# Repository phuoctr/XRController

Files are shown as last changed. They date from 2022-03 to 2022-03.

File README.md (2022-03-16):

# Tutorial: Thumb-mounted controller

This thumb-mounted controller is an input device for using in extended reality (XR) environments, it operates by sensing user’s thumb gestures in which thumb contact and movements are processed using the output data from 2 or more force sensitive resistors and a gyroscope, recognised gestures are send to a XR device via Bluetooth Low Energy.

## Materials

- Adafruit Feather nRF52840 sense: this is a bluetooth low energy (BLE) development board which comes with built-in accelerator, gyroscope and magnetometer. Another equivalent board is Arduino Nano 33 BLE. The Adafruit Feather Sense can be found at [Adafruit website](https://www.adafruit.com/product/4516)

- 2*Force sensitive resistors: resistors with minimum sensitve of 30gr is recommend for better gesture sensing. The force sensistive resistors can be purchased for example on [Mouser](https://eu.mouser.com/ProductDetail/Ohmite/FSR05CE?qs=0lSvoLzn4L9hUdjZ8RLKtw==).

- 2* 10,000Ohms resistors. The resistors can be bought easily from the internet.
- 3.3V Li-Po battery. For this controller, a 500mAH battery is used but it can also be powered by the microUSB port but keep it in mind that because the power consumption is not very significant so some battery banks will only work for few second before it stop powering the controller.
- A housing for the board: this housing is based on the board holder from Adafruit and a thumb cover to mount the controller on. The stl file for this housing can be found in this repo. This housing is modified from the [Adafruit Feather case](https://www.thingiverse.com/thing:1367270/files).
- A housing for the battery: a wrist band for mounting the battery. The stl file for this band can be found in this repo.

## Force Sensitive Resistors

Force sensitive resistors play an important role on this controller for touch recognition including swiping and pressing. To use the force sensors, we need to make a voltage divider circuit as the figure below, a 3V power is connect to one pin on each force sensor, and on the other pin the analog input and ground is connected.



## Arduino program

To program the Adafruit Feather Sense board, you need to use Arduino with Adafruit nRF52 library imported, the process can be done following this tutorial from Adafruit. Along with the nRF52 library, the Adafruit_LSM6DS33.h library need to be imported to Arduino to get output data from the gyroscope. After the Arduino IDE is set up, connect the board to your computer via microUSB cable, download this Arduino sketch  and run it. 
Housing

The housing comprises of two parts, one for holding the Feather Sense board and the other for mounting user’s thumb, under the thumb mount, the force sensitive parts of two force sensitive resistors are stiched as illustrated in the figure below:


The controller can be powered either by connecting to a computer or using an external battery, a battery wristband is designed for mounting the battery.

## Gestures
At the moment, this controller supports following gestures, in future version of the hardware and software I hope to include more gestures
- Swiping left/right on a touch zone
- Swiping up/down
- Quick press
- Long press

A working demo for this controller can be found [here](https://phuoctrinh.com/ar-input-prototype), in this demo an AR Unity application for iPad is developed which communicate with the XR controller over BLE.

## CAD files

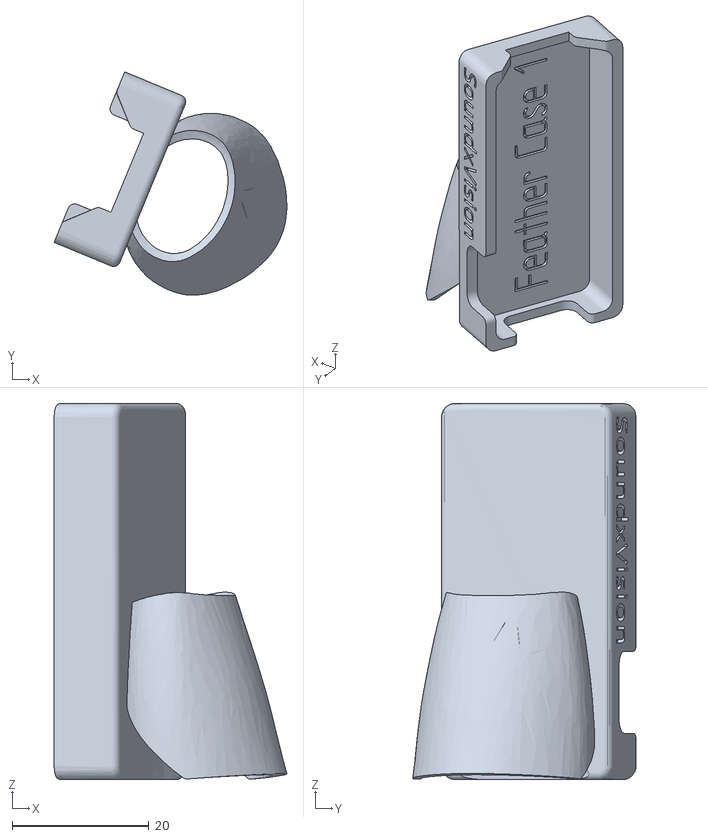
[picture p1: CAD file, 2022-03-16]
ThumbMountedDeviceHousing.stl
34.1 x 32.7 x 55.0

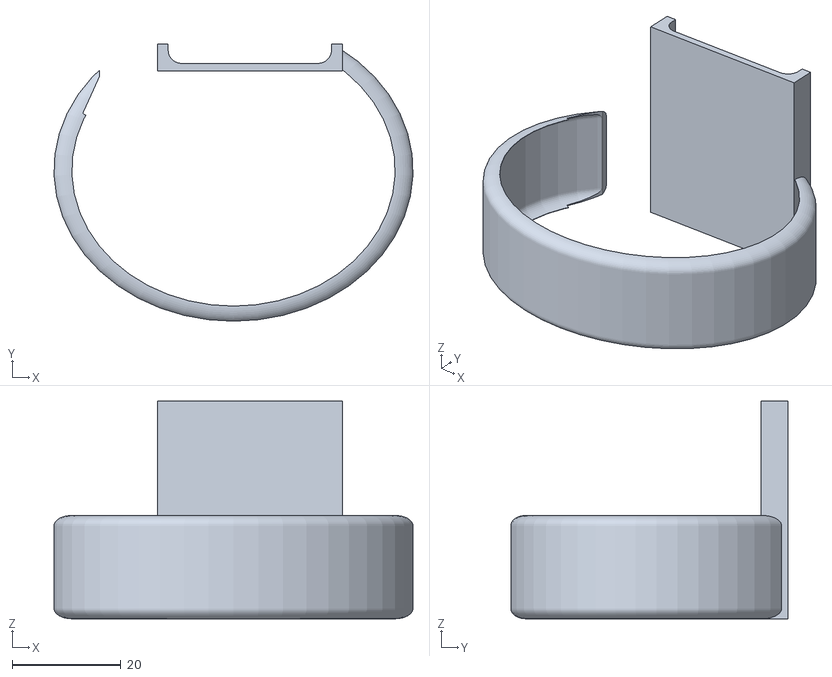
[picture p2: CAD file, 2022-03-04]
BatteryBand.stl
66.0 x 51.0 x 40.0

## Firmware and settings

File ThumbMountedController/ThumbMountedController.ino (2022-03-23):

#include <bluefruit.h>
#include "ThumbMountedController.h"
#include <Adafruit_LSM6DS33.h>  // Accel + gyro

//Sensors definition
Adafruit_LSM6DS33 lsm6ds33; // Gyro and Accel

// BLE Service
BLEService        service                    (HID_UUID(0x0000));
BLECharacteristic deviceInfoCharacteristic  (HID_UUID(0x0001));
BLECharacteristic hidCharacteristic (HID_UUID(0x0002));

int state = IDLING;
int timer0 = TOUCH_RELEASE_DURATION; // timer for touch releasing
int timer1 = SWIPING_UPDATE_INTERVAL; // time slot for angle calc
int timer2 = MINIMUM_PRESS_DOWN_DURATION; // timer for press sensing

// timer references
uint32_t timerRef0; // timestamp for touch releasing
uint32_t timerRef1; // timestamp for angle calc
uint32_t timerRef2; // timestamp for pressing

// touch release
bool firstPointRelease = false;
bool secondPointRelease = false;

//z Axis rotation
float zAxisRotation;

void setupSensors(void)
{
  
  lsm6ds33.begin_I2C(); // begin accel + gyro
  // set lowest range
  lsm6ds33.setGyroRange(LSM6DS_GYRO_RANGE_500_DPS);
  // Increase I2C speed to 400 Khz
  Wire.setClock(400000);
}

void setupBLE(void){
  const char deviceName[13] = "XRController";
  Bluefruit.configPrphBandwidth(BANDWIDTH_MAX);
  Bluefruit.begin();
  Bluefruit.setTxPower(4);    // Check bluefruit.h for supported values
  Bluefruit.setName(deviceName);
  service.begin();
  
  Bluefruit.Periph.setConnInterval(16, 24);
  Bluefruit.Periph.setConnectCallback(connect_callback);
  Bluefruit.Periph.setDisconnectCallback(disconnect_callback);

  hidCharacteristic.setProperties(CHR_PROPS_NOTIFY);
  hidCharacteristic.setPermission(SECMODE_OPEN, SECMODE_NO_ACCESS);
  hidCharacteristic.setFixedLen(1 * sizeof(byte)); //  data length for state, 1 byte
  hidCharacteristic.begin();
   
  }
  
void startAdv(void)
{
  // Advertising packet
  Bluefruit.Advertising.addFlags(BLE_GAP_ADV_FLAGS_LE_ONLY_GENERAL_DISC_MODE);
  Bluefruit.Advertising.addTxPower();

  // Include bleuart 128-bit uuid
  Bluefruit.Advertising.addService(service);
  Bluefruit.Advertising.addName();
  Bluefruit.Advertising.restartOnDisconnect(true);
  Bluefruit.Advertising.setInterval(32, 244);    // in unit of 0.625 ms
  Bluefruit.Advertising.setFastTimeout(30);      // number of seconds in fast mode
  Bluefruit.Advertising.start(0);                // 0 = Don't stop advertising after n seconds  
}




uint8_t updateState(void){
  // read the input on analog pin 0:
  int AIN0 = analogRead(A0); // first force sensor
  int AIN1 = analogRead(A1); // second force sensor
  
  sensors_event_t event; // gyro event
  lsm6ds33.getGyroSensor()->getEvent(&event);
  
  switch (state) {

    case IDLING: // Default state, listen for change on first and second force sensors
      if (AIN0 >= NORMAL_TOUCH || AIN1 >= NORMAL_TOUCH) state = TOUCHING;
      break;

    case TOUCHING: // When contact is detected on at least one force sensor
      if (AIN0 >= NORMAL_TOUCH && AIN1 >= NORMAL_TOUCH) break; // Not yet built
      // first point sensing
      if (AIN0 >= NORMAL_TOUCH && AIN0 < HARD_PRESS) { // Light-medium pressure on 1s force sensor
        state = FIRST_ZONE_TOUCHING; // Set state to swiping
        timerRef1 = millis(); // Start time reference for calculating z Axis rotation
      }
      else if (AIN0 >= HARD_PRESS){ 
        state = FIRST_ZONE_START_PRESS; // Hard press on first force sensor
        timerRef2 = millis();
      }
      // second point sensing
      if (AIN1 >= NORMAL_TOUCH && AIN1 < HARD_PRESS) { // Light-medium pressure on 2 force sensor
        state = SECOND_ZONE_TOUCHING; // Set state to swiping
        timerRef1 = millis();
      }
      else if (AIN1 >= HARD_PRESS) {
        state = SECOND_ZONE_START_PRESS; // Hard press on first force sensor
        timerRef2 = millis();
      }
      break;

    case FIRST_ZONE_TOUCHING:
      if (AIN0 <= NONE_CONTACT) { 
        // pressure down below 10 => touch release
        state = TOUCH_RELEASE;
        firstPointRelease = true;
        timerRef0 = millis(); // start timer
      }
      else if (AIN0 >= HARD_PRESS) { // pressure > 600 => pressing
        state = FIRST_ZONE_START_PRESS;
        timerRef2 = millis(); // timer ref for pressing
      }
      else {
        if (timer1 > 0) {
          zAxisRotation += event.gyro.z * SENSORS_RADS_TO_DPS * (millis() - timerRef1) / 1000;          // Integration from angular velocity to rotation
          timer1 -= millis() - timerRef1;
          timerRef1 = millis();
          if (zAxisRotation >= SWIPING_ANGLE) {
            state = FIRST_ZONE_LEFT;
            zAxisRotation = 0;
          }
          else if (zAxisRotation <= -SWIPING_ANGLE) {
            state = FIRST_ZONE_RIGHT;
            zAxisRotation = 0;
          }
        }
        else {
          timer1 = SWIPING_UPDATE_INTERVAL;
          zAxisRotation = 0;
        }
      }
      break;

    case FIRST_ZONE_LEFT:
      state = TOUCHING;
      break;

    case FIRST_ZONE_RIGHT:
      state = TOUCHING;
      break;

    case FIRST_ZONE_START_PRESS:
      // If pressure down to 10 and below, just switch to touch release
      if (AIN0 <= NONE_CONTACT){ 
        state = IDLING;
        break;
      }
      // The timer count down from 500
      if (timer2 > 0) {
        timer2 -= millis() - timerRef2; //On first time, the timerRef2 was initialized on TOUCHING
        timerRef2 = millis(); //Re-initialized for next loop
        if (AIN0 < HARD_PRESS) state = FIRST_ZONE_QUICK_PRESS; //if pressing shorter than 500ms => press once
      }
      else { 
          timer2 = 0;
          state = FIRST_ZONE_PRESS_DOWN;
      }
      break;

    case FIRST_ZONE_QUICK_PRESS:
      // Do something with single tap
      timer2 = MINIMUM_PRESS_DOWN_DURATION; // reset timer 2
      state = TOUCHING;
      break;

    case FIRST_ZONE_PRESS_DOWN:
      // keep state until force below 600
      if(AIN0 < HARD_PRESS) {
        state = TOUCHING;
        timer2 = MINIMUM_PRESS_DOWN_DURATION; // reset timer 2
        }
      break;

    case SECOND_ZONE_TOUCHING:
      if (AIN1 <= NONE_CONTACT) {
        state = TOUCH_RELEASE;
        secondPointRelease = true;
        timerRef0 = millis();
      }
      else if (AIN1 >= HARD_PRESS) {
        state = SECOND_ZONE_START_PRESS;
        timerRef2 = millis();
      }
      else {
        if (timer1 > 0) {
          zAxisRotation += event.gyro.z * SENSORS_RADS_TO_DPS * (millis() - timerRef1) / 1000;
          timer1 -= millis() - timerRef1;
          timerRef1 = millis();
          if (zAxisRotation >= SWIPING_ANGLE/2) {
            state = SECOND_ZONE_LEFT;
            zAxisRotation = 0;
            Serial.println(">>>>>>>>>>>>>>>>>>>>>>>>>>>>>>>>>>>>>>>>>>>>>>>>>>>>>>>");
          }
          else if (zAxisRotation <= -SWIPING_ANGLE/3) {
            state = SECOND_ZONE_RIGHT;
            zAxisRotation = 0;
            Serial.println("<<<<<<<<<<<<<<<<<<<<<<<<<<<<<<<<<<<<<<<<<<<<<<<<<<<<<<<");
          }
        }
        else {
          timer1 = SWIPING_UPDATE_INTERVAL;
          zAxisRotation = 0;
        }
      }
      break;

    case SECOND_ZONE_LEFT:
      //Do sth
      state = TOUCHING;
      break;

    case SECOND_ZONE_RIGHT:
      //Do sth
      state = TOUCHING;
      break;

    case SECOND_ZONE_START_PRESS:
//      // If pressure down to 10 and below, just switch to switch release
      if (AIN1 <= NONE_CONTACT){ 
        state = IDLING;
        break;
      }
//      // The timer count down for the duration of defined minimum press down duration
      if (timer2 > 0) {
        timer2 -= millis() - timerRef2; //On first time, the timerRef2 was initialized on TOUCHING
        timerRef2 = millis(); //Re-initialized for next loop
        if (AIN1 < HARD_PRESS) state = SECOND_ZONE_QUICK_PRESS; //if pressing shorter than 100ms => press once
      }
      else { 
        timer2 = 0;
        state = SECOND_ZONE_PRESS_DOWN;
      }
      break;

    case SECOND_ZONE_QUICK_PRESS:
      // Do something with single tap
      timer2 = MINIMUM_PRESS_DOWN_DURATION; // reset timer 2
      state = TOUCHING;
      break;

    case SECOND_ZONE_PRESS_DOWN:
      // keep state until force below 600
      if(AIN1 < HARD_PRESS) {
        state = TOUCHING;
        timer2 = MINIMUM_PRESS_DOWN_DURATION; // reset timer 2
        }
      break;
      
    case TOUCH_RELEASE:
      timer0 -= (millis() - timerRef0);
      timerRef0 = millis();
      if (timer0 <= 0){
          timer0 = TOUCH_RELEASE_DURATION;
          state = IDLING;
          // After touch release interval without any touch, reset first/secondTouchRelease bool
          firstPointRelease = false; 
          secondPointRelease = false;
        }
      else{
        if(firstPointRelease && AIN1 > NONE_CONTACT){
          firstPointRelease = false;
          timer0 = TOUCH_RELEASE_DURATION;
          state = UP;
          break;
          }
        if(secondPointRelease && AIN0 >= NONE_CONTACT){
          secondPointRelease = false;
          timer0 = TOUCH_RELEASE_DURATION;
          state = DOWN;
          break;
          }
        }
      break;

    case UP:
        state = IDLING;
        break;

    case DOWN:
        state = IDLING;
        break;
  }
  
  //Plot
  #if defined(HID_DEBUG_OUTPUT)
  Serial.print(AIN0);
  Serial.print(",");
  Serial.print(AIN1);
  Serial.print(",");
  //Serial.print(timer0);
  //Serial.print(",");
  Serial.println(state * 100);
  #endif

  #if defined(FORCE_SENSORS_DEBUG)
  Serial.print(AIN0);
  Serial.print(",");
  Serial.print(AIN1);
  Serial.print(",");
  Serial.println(timer2);
  #endif


  return state;
  }
  
void updateSubscribedCharacteristics(void)
{
  if(hidCharacteristic.notifyEnabled()) {
    byte data[1];
    data[0] = updateState();
    hidCharacteristic.notify(data, hidCharacteristic.getMaxLen()); //notify state of the periph
  }
}
void setup() {
  setupSensors();
  setupBLE();
  startAdv();
}

void loop() {  
  if (Bluefruit.connected())
  {
    updateSubscribedCharacteristics();
  }
  
#if defined(HID_DEBUG_OUTPUT) || defined(FORCE_SENSORS_DEBUG)
   updateState();
   delay(10);
#endif
}

// callback invoked when central connects
void connect_callback(uint16_t conn_handle)
{
  // Get the reference to current connection
  BLEConnection* connection = Bluefruit.Connection(conn_handle);

  char central_name[32] = { 0 };
  connection->getPeerName(central_name, sizeof(central_name));

  Serial.print("Connected to ");
  Serial.println(central_name);
}

/**
 * Callback invoked when a connection is dropped
 * @param conn_handle connection where this event happens
 * @param reason is a BLE_HCI_STATUS_CODE which can be found in ble_hci.h
 */
void disconnect_callback(uint16_t conn_handle, uint8_t reason)
{
  (void) conn_handle;
  (void) reason;

  Serial.println();
  Serial.print("Disconnected, reason = 0x"); Serial.println(reason, HEX);
}

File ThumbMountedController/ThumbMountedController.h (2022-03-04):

//Debug
//#define HID_DEBUG_OUTPUT
//#define FORCE_SENSORS_DEBUG


#define HID_UUID(val)  \
  (const uint8_t[]) {  \
    0xe8, 0x74, 0x2c, 0x65, 0xf0, 0x01, 0x38, 0x95,  \
    0x7a, 0x46, (uint8_t) (val & 0xff), (uint8_t) (val >> 8), 0x02, 0x00, 0x5a, 0x55   \
  }

enum TouchState
{
  IDLING, 
  TOUCHING, 
  FIRST_ZONE_TOUCHING, 
  FIRST_ZONE_LEFT, 
  FIRST_ZONE_RIGHT, 
  FIRST_ZONE_START_PRESS,
  FIRST_ZONE_QUICK_PRESS,
  FIRST_ZONE_PRESS_DOWN, 
  SECOND_ZONE_TOUCHING,
  SECOND_ZONE_LEFT, 
  SECOND_ZONE_RIGHT, 
  SECOND_ZONE_START_PRESS, 
  SECOND_ZONE_QUICK_PRESS, 
  SECOND_ZONE_PRESS_DOWN, 
  TOUCH_RELEASE, 
  UP, 
  DOWN, 
};

// Pressure 
#define NONE_CONTACT 10 // <10: none contact, just ground noise
#define NORMAL_TOUCH 50 // 50-599: normal touch
#define HARD_PRESS 600 // >= 600: hard press


// State 
#define SWIPING_UPDATE_INTERVAL 2000
#define TOUCH_RELEASE_DURATION 100
#define SWIPING_ANGLE 15 // degrees
#define MINIMUM_PRESS_DOWN_DURATION 250 // miliseconds

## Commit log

2022-03-04 Added Arduino sketch
    [BatteryBand.stl, ThumbMountedDeviceHousing.stl]
2022-03-04 Added STL files for housings
    [BatteryBand.stl, ThumbMountedDeviceHousing.stl]
2022-03-16 Update the device housing for better fit
    [ThumbMountedControllerHousing.stl]
